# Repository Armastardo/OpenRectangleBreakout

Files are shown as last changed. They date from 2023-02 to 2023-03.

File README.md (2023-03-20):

# Open Rectangle Breakout
RaspberryPi Pico-powered breakout board for a stickless controller
  
<p align="center">
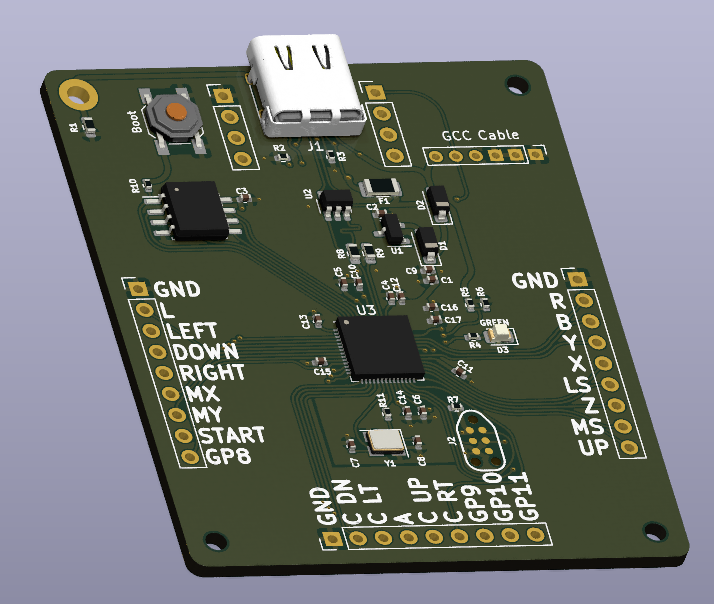
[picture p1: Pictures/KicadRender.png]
  
</p>

<p align="center">
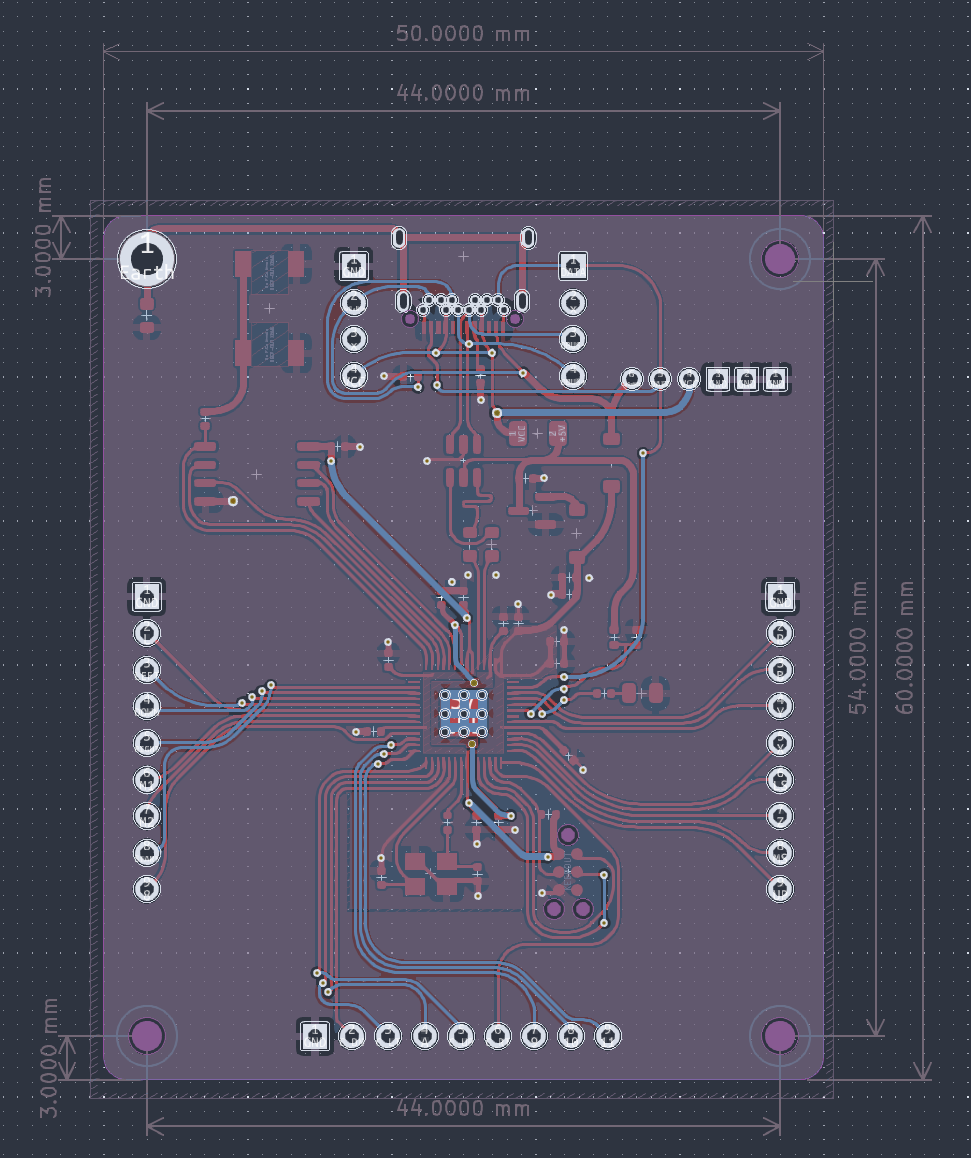
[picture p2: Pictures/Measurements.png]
  
</p>

Design files are available in this repository. Production files for JLCPCB in the releases page. Currently untested.

## Table of contents
* [Features](#features)
* [Usage](#usage)
* [To-do](#to-do)
* [Acknowledgements](#acknowledgements)

## Features
- USB-C to GCC and USB-C to N64 cable compatible with integrated port or with a [Model-U](https://github.com/Crane1195/Model-U).
- Can use non detachable OEM/Third party gamecube cables.
- Uses [HayBox](https://github.com/JonnyHaystack/HayBox) and [Pico Rectangle](https://github.com/JulienBernard3383279/pico-rectangle) default pinout. Labeled accordingly with some extra pins broken out if you want to expand functionality (WASD layout, add another LED, etc).

## Usage
1. Order via JLCPCB using the production files in the releases page.
	- Solder screw terminals if prefered.
2. Connect them to the PC and the first time it'll show up as a mass storage device.
3. Drop your prefered firmware in uf2 format and once it disconnects it should be good to go.
	- If you connect while pressing the BOOT button, it'll show again as a mass storage device so you can update the firmware or replace it.

## To-do:
- Use it in a build! Please share pics if you do so. My discord username is Quark#0009

### Made using the Open Rectangle Template
OpenRectangleTemplate project] - https://github.com/Armastardo/OpenRectangleTemplate

This was just a proof of concept to see how easy it is to use the template. It's good! But I still need to work on both projects to get them to where I want.

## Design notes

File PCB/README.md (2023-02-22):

# Open Rectangle Template
**RP2040 template for use with box style controllers for the GC - CURRENTLY UNTESTED**

<p align="center">
  
</p>

## Table of contents
* [About](#about)
* [Usage](#usage)
* [To-do](#to-do)
* [Acknowledgements](#acknowledgements)

## About
This template was created for the purpose of easing development of box-styled controllers (rectangles) that work with a GameCube console and Nintendo 64 via a USB C to console cable. It uses a RP2040 as its main controller so compatibility to other devices will be limited to the firmware you are using. (Such as [HayBox](https://github.com/JonnyHaystack/HayBox), [Pico-Rectangle](https://github.com/JulienBernard3383279/pico-rectangle), etc). There's already a footprint added for a compatible USB-C port that will allow you to used said cables, as well as a USB C to C cable, or C to A cable for PC or Switch.

## Usage
This templates requires for you to have a minium experience with Kicad and some EE basics. You can just download it as *.zip and start creating your own. Make sure you are using **Kicad 7**. The most finicky part of the template is 
### Changes from the Raspberry Pi Pico
~~This template is not 1:1 with the Raspberry Pi Pico, so you will need to change some of the default pins in order to this to work. For example:~~
~~- VBUS sensing on the pico is GPIO24, while the template has it on GPIO28.~~
~~- PICO_LED is on GPIO25 on pico, while the template has it on GPIO27.~~
~~- Default pinout for GC has the data pin , template has it on GPIO29.~~

~~All of these changes can be seen (an edited!) in the schematic and the pcb. This was made only for convenience with the wiring. *You should recompile the firmware you're planning on use to accomodate for these changes.*~~
Reverted back to original Pico wiring! Thanks for the feedback!

## To-do:
- Prototype it! It's currently untested. Most of the design is tested except:
	- C to C functionality
	- VBUS sensing
	- LED
- Add LCSC part number to every component.
- Write a more extensive guide.

## Acknowledgements:
- [@Sleepdealr](https://github.com/Sleepdealr/) - For creating the [RP2040 design guide](https://github.com/Sleepdealr/RP2040-designguide) which this template is mostly based from
- Crane's Lab - For having such an amazing community and inspiring creativity in everyone who steps there.
- [@rana-sylvatica](https://github.com/rana-sylvatica/) - For making the OFOF1/Rana Digital and inspiring me to design my rectangles.
- [@Ryanemzed](https://github.com/Ryanemzed/) - For posting a cool clear acrylic build and taking me into a new rabbit hole (and being an amazing community member!).
- The Phob project - For being an amazing standard for the open source-community.

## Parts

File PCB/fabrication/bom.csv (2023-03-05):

Designator | Footprint | Quantity | Value | LCSC Part #
C1 | 402 | 1 | 1uF | C52923
C10 | 402 | 1 | 1uF | C52923
C11 | 402 | 1 | 100nF | C1525
C12 | 402 | 1 | 100nF | C1525
C13 | 402 | 1 | 100nF | C1525
C14 | 402 | 1 | 100nF | C1525
C15 | 402 | 1 | 100nF | C1525
C16 | 402 | 1 | 100nF | C1525
C17 | 402 | 1 | 100nF | C1525
C2 | 402 | 1 | 1uF | C52923
C3 | 402 | 1 | 100nF | C1525
C4 | 402 | 1 | 1uF | C52923
C5 | 402 | 1 | 100nF | C1525
C6 | 402 | 1 | 100nF | C1525
C7 | 402 | 1 | 22pF | C1555
C8 | 402 | 1 | 22pF | C1555
C9 | 402 | 1 | 10uF | C15525
D1, D2 | D_SOD-123 | 2 | Schottky Diode | C8598
D3 | 805 | 1 | GREEN | C2297
F1 | 1206 | 1 | 500 mA | C70076
J1 | TYPE-C_24P_QCHT | 1 | USB C Connector | C456013
R1 | 603 | 1 | 1M | C25190
R10 | 402 | 1 | 1k | C11702
R11 | 402 | 1 | 1k | C11702
R2 | 402 | 1 | 5.1k | C25744
R3 | 402 | 1 | 5.1k | C25744
R4 | 402 | 1 | 470 | C25117
R5 | 402 | 1 | 5.6k | C25908
R6 | 402 | 1 | 10k | C25744
R7 | 402 | 1 | 10k | C25744
R8 | 603 | 1 | 27 | C25190
R9 | 603 | 1 | 27 | C25190
U1 | SOT-23 | 1 | XC6206 | C5446
U2 | SOT-23-6 | 1 | USBLC6-2SC6 | C323793
U3 | RP2040-QFN-56 | 1 | RP2040 | C2040
U4 | SOIC-8_5.23x5.23mm_P1.27mm | 1 | W25Q128JVS | C97521
Y1 | Crystal_SMD_3225-4Pin_3.2x2.5mm | 1 | 12MHz | C9002
SW1 | Button_Switch_SMD:SW_SPST_SKQG_WithStem | 1 | Boot | C202424

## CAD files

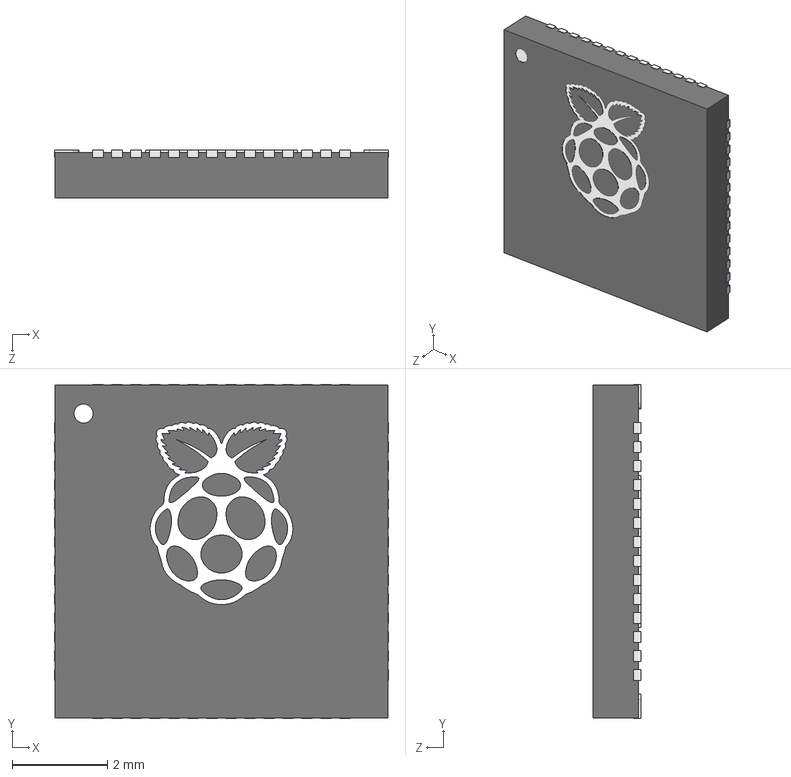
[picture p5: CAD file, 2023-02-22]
PCB/model/RP2040_QFN_PACKAGE.STEP
7.02 x 7.02 x 1.00 mm

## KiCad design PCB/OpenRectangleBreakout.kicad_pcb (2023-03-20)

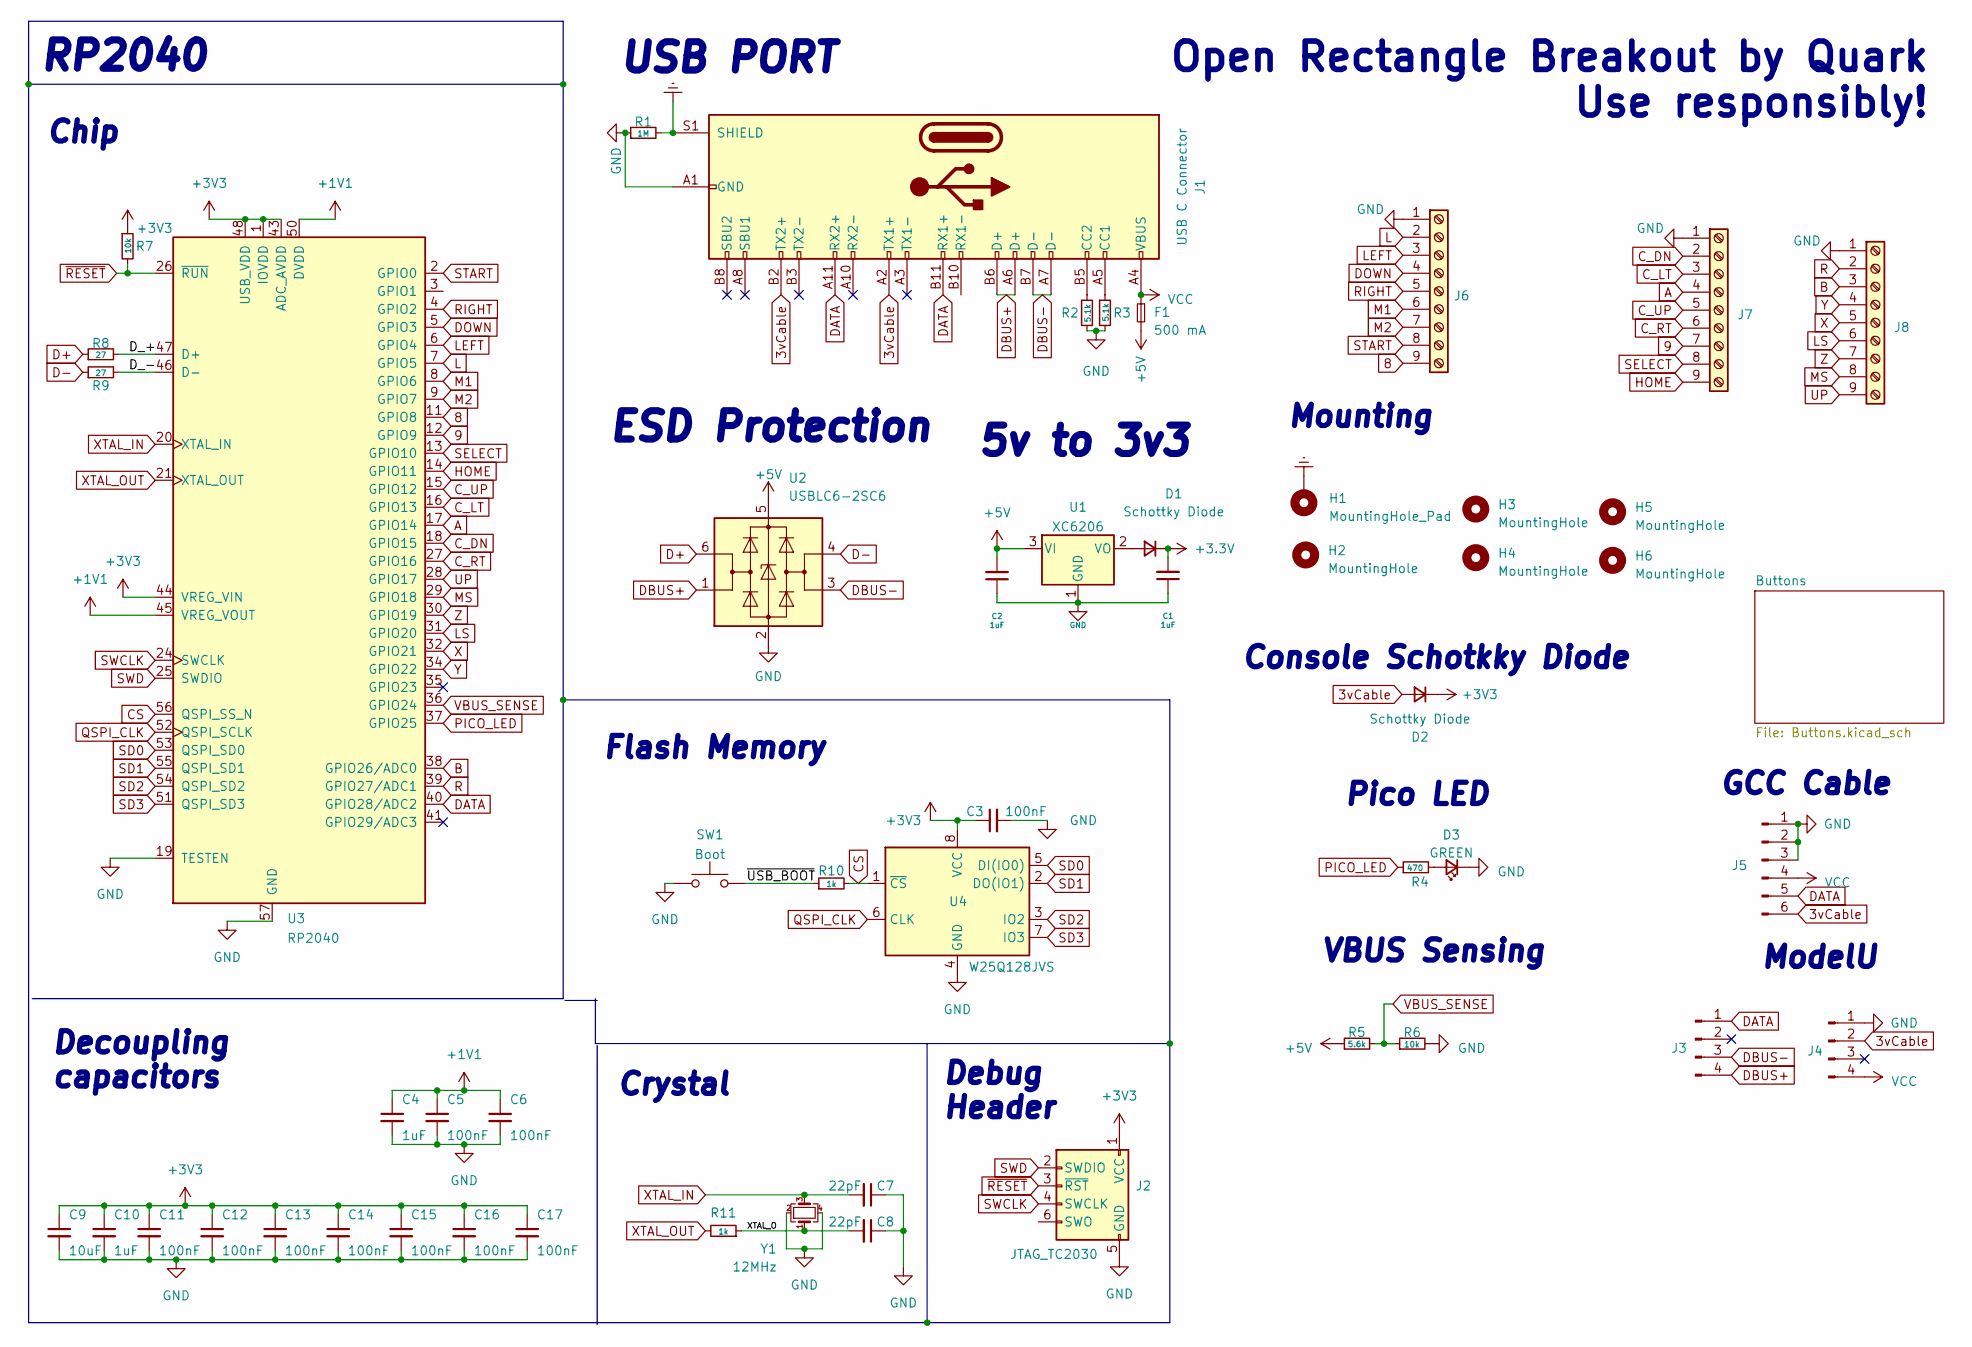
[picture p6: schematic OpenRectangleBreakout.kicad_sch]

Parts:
C1, C2, C4, C10: 1uF; C_0402_1005Metric; LCSC C52923
C3, C5, C6, C11, C12, C13, C14, C15, C16, C17: 100nF; C_0402_1005Metric; LCSC C1525
C7, C8: 22pF; C_0402_1005Metric; LCSC C1555
C9: 10uF; C_0402_1005Metric; LCSC C15525
D1, D2: Schottky Diode; D_SOD-123; LCSC C130880
D3: GREEN; LED_0805_2012Metric; LCSC C2297
F1: 500 mA; Fuse_1206_3216Metric
H1: MountingHole_Pad; MountingHole_2.2mm_M2_ISO14580_Pad
H2, H3, H4, H5, H6: MountingHole; MountingHole_2.1mm
J1: USB C Connector; TYPE-C_24P_QCHT; LCSC C456013
J2: JTAG_TC2030; CON_TC2030_outlined
J3, J4: Conn_01x04_Pin; PinHeader_1x04_P2.54mm_Vertical
J5: GCC Cable; PinHeader_1x06_P2.00mm_Vertical
J6, J7, J8: Screw_Terminal_01x09; PinHeader_1x09_P2.54mm_Vertical
R1: 1M; R_0603_1608Metric; LCSC C25190
R2, R3: 5.1k; R_0402_1005Metric; LCSC C25744
R4: 470; R_0402_1005Metric; LCSC C25117
R5: 5.6k; R_0402_1005Metric
R6: 10k; R_0402_1005Metric
R7: 10k; R_0402_1005Metric; LCSC C25744
R8, R9: 27; R_0603_1608Metric; LCSC C25190
R10, R11: 1k; R_0402_1005Metric; LCSC C11702
SW1: Boot; SW_SPST_SKQG_WithStem; LCSC C5156480
U1: XC6206; SOT-23; LCSC C5446
U2: USBLC6-2SC6; SOT-23-6
U3: RP2040; RP2040-QFN-56; LCSC C2040
U4: W25Q128JVS; SOIC-8_5.23x5.23mm_P1.27mm; LCSC C97521
Y1: 12MHz; Crystal_SMD_3225-4Pin_3.2x2.5mm; LCSC C9002

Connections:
3vCable: D2.2 (A), J1.A2 (TX1+), J1.B2 (TX2+), J4.2, J5.6
8: J6.9, U3.11 (GPIO8)
9: J7.7, U3.12 (GPIO9)
+1V1: C4.1, C5.1, C6.1, U3.23 (DVDD), U3.45 (VREG_VOUT), U3.50 (DVDD)
+5V: C2.2, F1.2, R5.1, U1.3 (VI), U2.5 (VBUS)
/D_+: R8.2, U3.47 (D+)
/D_-: R9.2, U3.46 (D-)
/XTAL_O: C8.2, R11.1, Y1.1
/~USB_BOOT: R10.1, SW1.2
A: J7.4, U3.17 (GPIO14)
B: J8.3, U3.38 (GPIO26/ADC0)
CS: R10.2, U3.56 (QSPI_SS_N), U4.1 (~CS)
C_DN: J7.2, U3.18 (GPIO15)
C_LT: J7.3, U3.16 (GPIO13)
C_RT: J7.6, U3.27 (GPIO16)
C_UP: J7.5, U3.15 (GPIO12)
D+: R8.1, U2.6 (I/O1)
D-: R9.1, U2.4 (I/O2)
DATA: J1.A11 (RX2+), J1.B11 (RX1+), J3.1, J5.5, U3.40 (GPIO28/ADC2)
DBUS+: J1.A6 (D+), J1.B6 (D+), J3.4, U2.1 (I/O1)
DBUS-: J1.A7 (D-), J1.B7 (D-), J3.3, U2.3 (I/O2)
DOWN: J6.4, U3.5 (GPIO3)
Earth: H1.1, J1.S1 (SHIELD), R1.2
GND: C1.1, C2.1, C3.2, C4.2, C5.2, C6.2, C7.1, C8.1, C9.2, C10.2, C11.2, C12.2, C13.2, C14.2, C15.2, C16.2, C17.2, D3.1 (K), J1.A1 (GND), J1.A12 (GND), J1.B1 (GND), J1.B12 (GND), J2.5 (GND), J4.1, J5.1, J5.2, J5.3, J6.1, J7.1, J8.1, R1.1, R2.1, R3.2, R6.2, SW1.1, U1.1 (GND), U2.2 (GND), U3.19 (TESTEN), U3.57 (GND), U4.4 (GND), Y1.2, Y1.4
HOME: J7.9, U3.14 (GPIO11)
L: J6.2, U3.7 (GPIO5)
LEFT: J6.3, U3.6 (GPIO4)
LS: J8.6, U3.31 (GPIO20)
M1: J6.6, U3.8 (GPIO6)
M2: J6.7, U3.9 (GPIO7)
MS: J8.8, U3.29 (GPIO18)
unnamed: D1.2 (A), U1.2 (VO)
unnamed: D3.2 (A), R4.2
unnamed: J1.A5 (CC1), R3.1
unnamed: J1.B5 (CC2), R2.2
PICO_LED: R4.1, U3.37 (GPIO25)
QSPI_CLK: U3.52 (QSPI_SCLK), U4.6 (CLK)
R: J8.2, U3.39 (GPIO27/ADC1)
RIGHT: J6.5, U3.4 (GPIO2)
SD0: U3.53 (QSPI_SD0), U4.5 (DI(IO0))
SD1: U3.55 (QSPI_SD1), U4.2 (DO(IO1))
SD2: U3.54 (QSPI_SD2), U4.3 (IO2)
SD3: U3.51 (QSPI_SD3), U4.7 (IO3)
SELECT: J7.8, U3.13 (GPIO10)
START: J6.8, U3.2 (GPIO0)
SWCLK: J2.4 (SWCLK), U3.24 (SWCLK)
SWD: J2.2 (SWDIO), U3.25 (SWDIO)
UP: J8.9, U3.28 (GPIO17)
VBUS_SENSE: R5.2, R6.1, U3.36 (GPIO24)
VCC: F1.1, J1.A4 (VBUS), J1.A9 (VBUS), J1.B4 (VBUS), J1.B9 (VBUS), J4.4, J5.4
X: J8.5, U3.32 (GPIO21)
XTAL_IN: C7.2, U3.20 (XTAL_IN), Y1.3
XTAL_OUT: R11.2, U3.21 (XTAL_OUT)
Y: J8.4, U3.34 (GPIO22)
Z: J8.7, U3.30 (GPIO19)
~RESET: J2.3 (~RST), R7.2, U3.26 (~RUN)

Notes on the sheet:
Console Schotkky Diode
Crystal
USB PORT
Flash Memory
ModelU
Pico LED
Mounting
Open Rectangle Breakout by Quark Use responsibly!
RP2040
GCC Cable
Debug Header
VBUS Sensing
Chip
5v to 3v3
ESD Protection
Decoupling capacitors

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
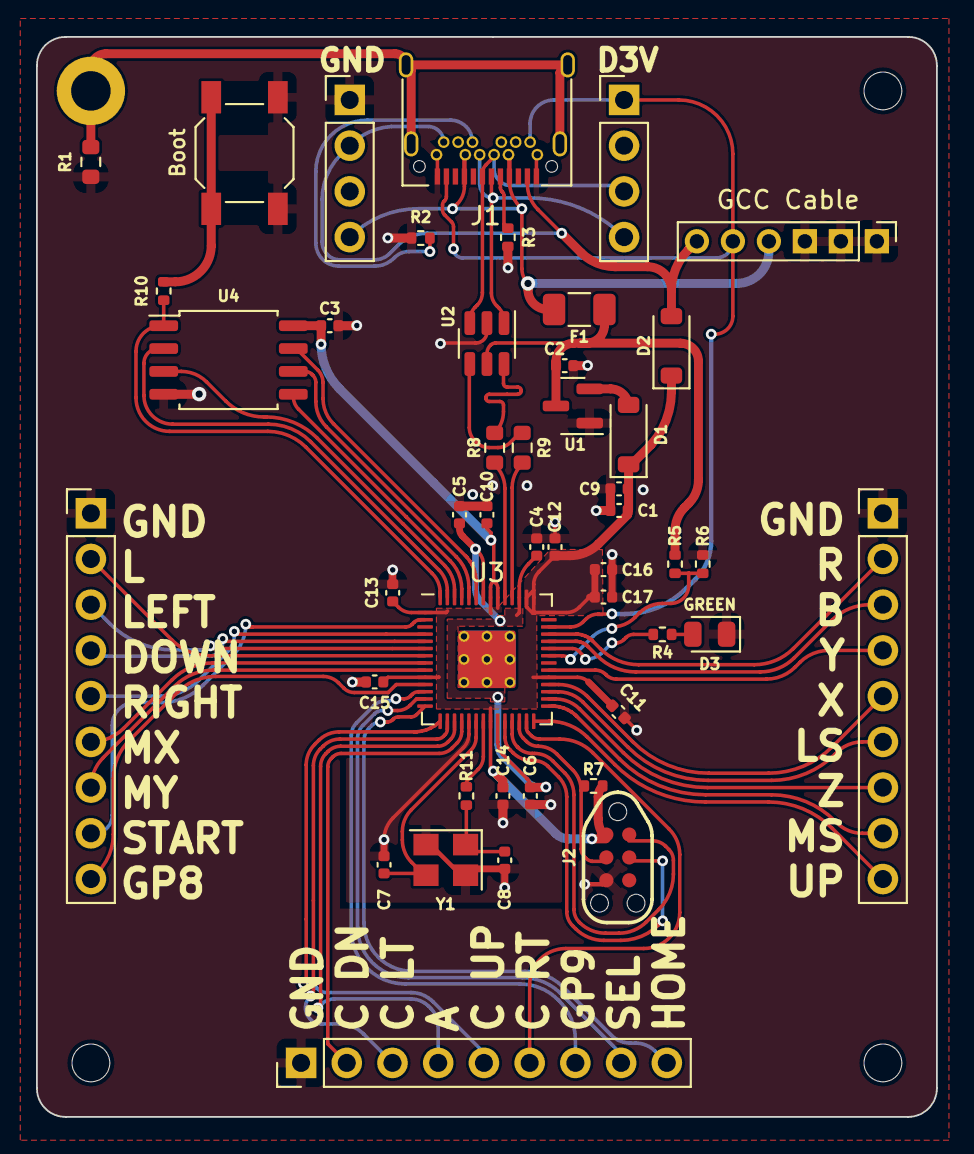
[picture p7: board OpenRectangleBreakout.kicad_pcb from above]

Board: 2 copper layers, 50.0 x 60.0 mm, 50 parts (0 on the bottom side), 57 nets.

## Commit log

2023-03-05 First version
    [OpenRectangleBreakout-B_Cu.gbr, OpenRectangleBreakout-B_Mask.gbr, OpenRectangleBreakout-B_Paste.gbr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]
2023-03-05 Fixed the POS file
    [positions.csv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]
2023-03-20 Fixed START button to the correct pin
    [OpenRectangleBreakout-B_Cu.gbr, OpenRectangleBreakout-B_Mask.gbr, OpenRectangleBreakout-B_Paste.gbr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]
